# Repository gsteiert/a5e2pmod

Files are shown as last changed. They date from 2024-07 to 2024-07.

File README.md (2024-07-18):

# A MicroSD and PMOD adapter for the Agilex 5 E-Series Premium Devkit

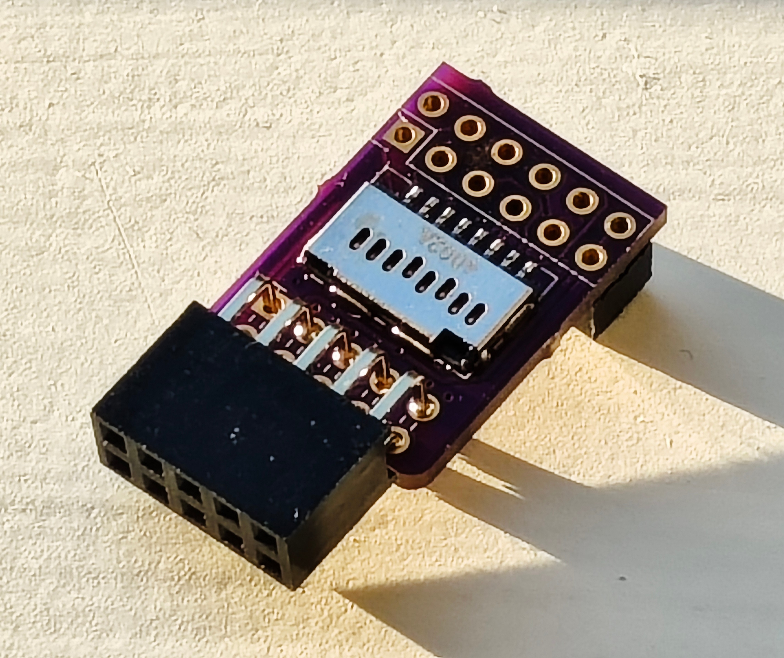
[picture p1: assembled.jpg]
Picture of assembled board


## Schematic

[View the schematic online in KiCanvas](https://kicanvas.org/?github=https%3A%2F%2Fgithub.com%2Fgsteiert%2Fa5e2pmod%2Fblob%2Fmain%2Fa5e2pmod.kicad_sch)

## Pinout

|  Agilex 5 |  J9  |  PMOD  |  Micro SD  |
| --- | ---- | --- | --- |
|  3.3V |  1 |  11,12 | 4 VDD |
|  BU31  HVIO_6A_5  |  2 |  1 | 2 DAT3/CD  |
|  BU28  HVIO_6A_1  |  3 |  2 | 8 DAT1 |
|  BM28  HVIO_6A_6  |  4 |  3 | 3 CMD |
|  BP31  HVIO_6A_2  |  5 |  4 | 1 DAT2 |
|  BF21  HVIO_6B_1  |  6 |  5 | 7 DAT0 |
|  BR28  HVIO_6A_3  |  7 |  6 | 9 DET |
|  BM31  HVIO_6A_8  |  8 |  7 | 5 CLK |
|  BR31  HVIO_6A_4  |  9 |  8 | - |
|  GND |  10  |  9,10  | 6 VSS |

## PMOD

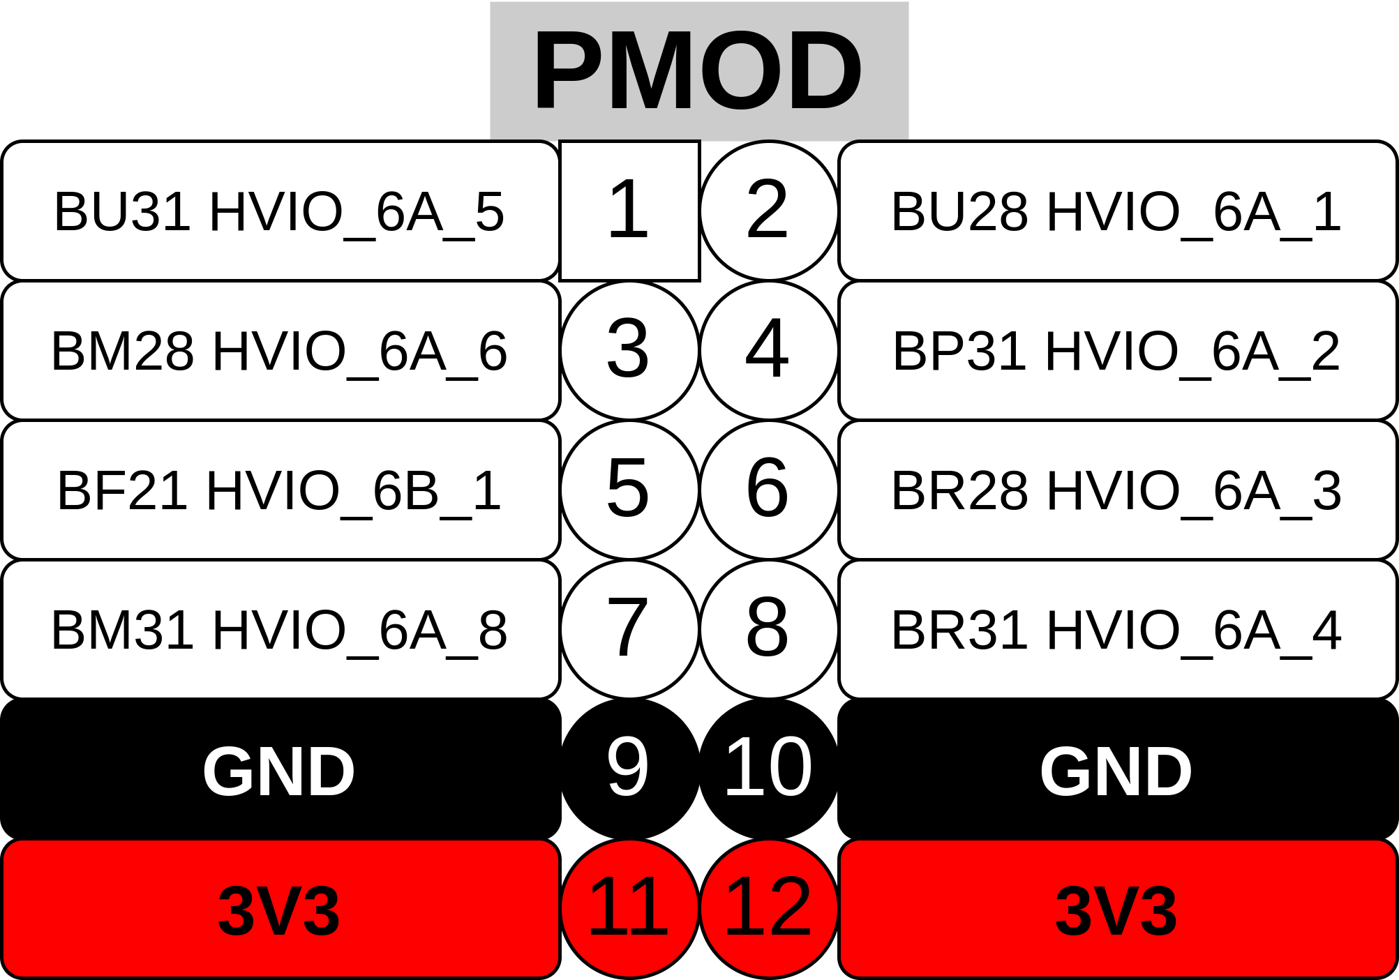
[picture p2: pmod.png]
PMOD Pinout


## Installed

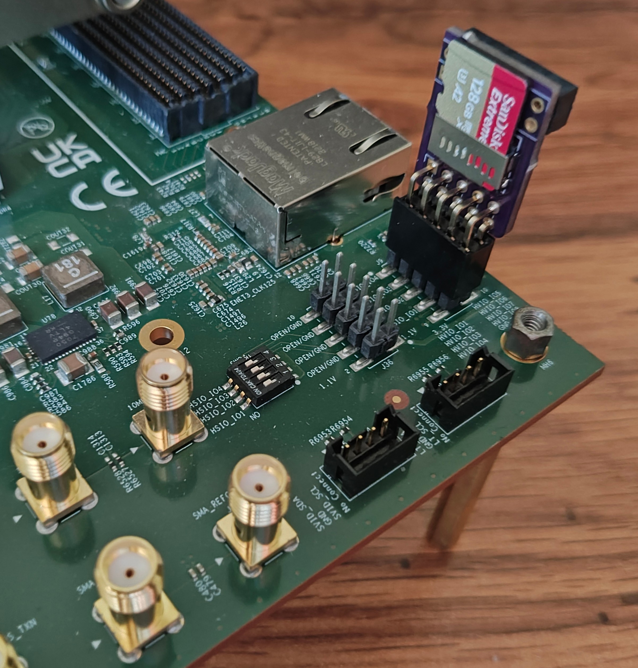
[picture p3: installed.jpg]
Picture of the board installed


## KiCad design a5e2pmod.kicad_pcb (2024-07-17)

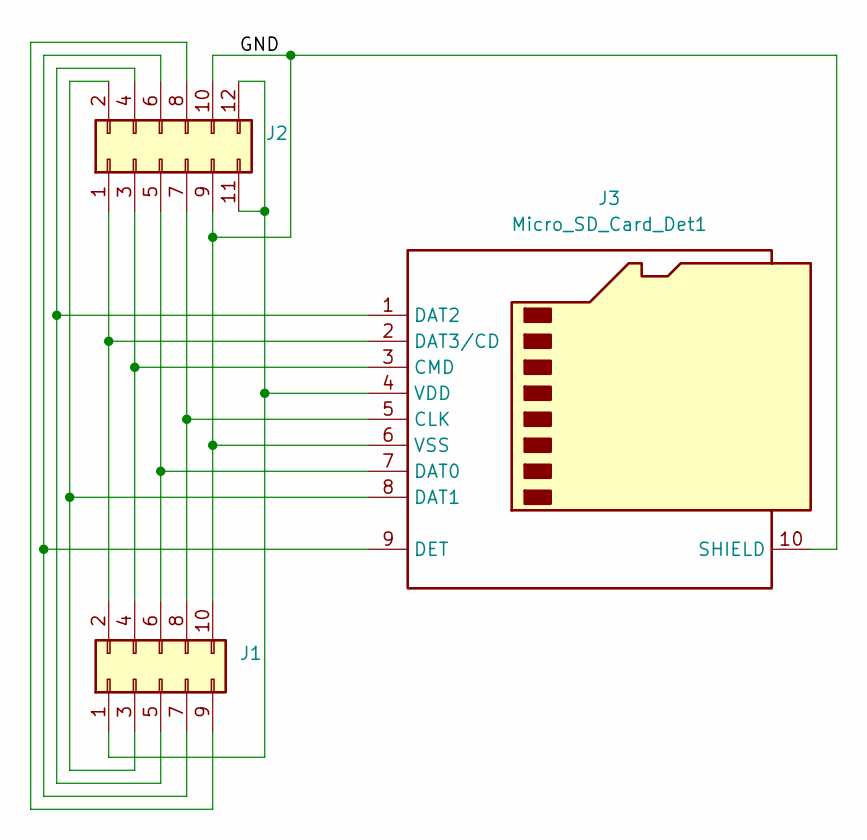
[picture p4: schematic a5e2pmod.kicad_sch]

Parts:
J1: Conn_02x05_Odd_Even; PinSocket_2x05_P2.54mm_Horizontal
J2: Conn_02x06_Odd_Even; PMOD_Hybrid
J3: Micro_SD_Card_Det1; 105162-0001_MOL

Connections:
/GND: J1.10, J2.9, J2.10, J3.6 (VSS), J3.10 (SHIELD)
unnamed: J1.1, J2.11, J2.12, J3.4 (VDD)
unnamed: J1.2, J2.1, J3.2 (DAT3/CD)
unnamed: J1.3, J2.2, J3.8 (DAT1)
unnamed: J1.4, J2.3, J3.3 (CMD)
unnamed: J1.5, J2.4, J3.1 (DAT2)
unnamed: J1.6, J2.5, J3.7 (DAT0)
unnamed: J1.7, J2.6, J3.9 (DET)
unnamed: J1.8, J2.7, J3.5 (CLK)
unnamed: J1.9, J2.8

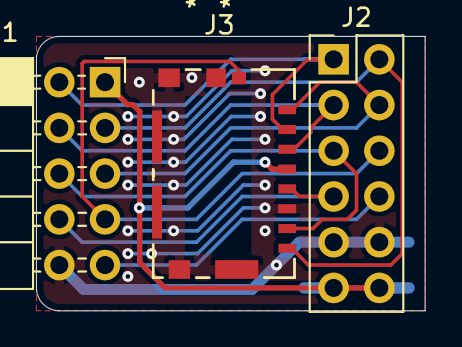
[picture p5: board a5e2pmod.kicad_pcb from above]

Board: 2 copper layers, 21.6 x 15.2 mm, 3 parts (0 on the bottom side), 10 nets.
